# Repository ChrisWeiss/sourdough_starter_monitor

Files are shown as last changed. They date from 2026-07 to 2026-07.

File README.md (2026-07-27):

# Sourdough Starter Monitor (BLE / BTHome)

Battery-oriented remake of [twilio/sourd.io](https://github.com/twilio/sourd.io): temperature, humidity, and rise (**VL53L1X ToF** distance) for a sourdough starter jar.

Instead of Twilio Narrowband cellular, the jar node **advertises BTHome v2 over BLE**. Home Assistant ingests the readings; an automation republishes **sourd.io-style JSON** to your existing MQTT broker.

## Hardware

| Role | Prototype | Production |
|---|---|---|
| MCU | Lolin / WeMos ESP32-WROOM DevKit | nRF52840 (Pro Micro / SuperMini, Feather, or XIAO) + LiPo |
| Climate | BME280 (I2C; BMP280 fallback: no humidity) | same |
| Distance | VL53L1X ToF (I2C) | same; keep lid-to-dough ≥ ~30–40 mm |
| Enclosure | Bench wiring | sourd.io v2.5 jar stack + remixed lid insert |

See [docs/wiring.md](docs/wiring.md) (WireViz assembly diagrams) and [docs/bringup.md](docs/bringup.md). Regenerate diagrams with `./scripts/render_wiring.sh`.

## Firmware

PlatformIO project in [`firmware/`](firmware/). Use the project virtualenv (PlatformIO + WireViz):

```bash
./scripts/setup_venv.sh
source .venv/bin/activate

# One-shot build + flash + monitor (auto-detects USB serial)
./scripts/bringup_esp32.sh          # Lolin ESP32 prototype
./scripts/bringup_nrf52840.sh       # Pro Micro nRF52840 (default)

cd firmware
pio run -e lolin-esp32          # build prototype
pio run -e nrf52840             # Adafruit Feather
pio run -e nrf52840-xiao        # Seeed XIAO nRF52840
pio run -e nrf52840-promicro    # Pro Micro / SuperMini nRF52840
```

Duty cycle: wake → read sensors → advertise ~1.5 s → sleep (**90 s** on all envs, `SAMPLE_INTERVAL_SEC`).

## Home Assistant + MQTT

1. Discover the BTHome device (name `sourdough`).
2. Automation **Sourdough BTHome → MQTT** republishes to the broker (see [ha/](ha/)).
3. Subscribe to `sourdough/sourdough/state`:

```json
{"humidity":55.2,"temp":24.5,"distance":12,"battery":97,"pressure":1013.25}
```

Details: [docs/home-assistant.md](docs/home-assistant.md), [ha/README.md](ha/README.md).

## Enclosure

Vendored sourd.io STLs plus OpenSCAD remix and rendered adapters: [enclosure/README.md](enclosure/README.md).

```bash
./scripts/render_enclosure.sh
```

## License

Firmware and project docs: Apache-2.0 (aligned with sourd.io). Vendored enclosure STLs retain upstream Apache-2.0 copyright from Christine Sunu / Twilio sourd.io.

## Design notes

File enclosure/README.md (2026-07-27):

# Enclosure

## Vendored sourd.io v2.5

STL files in [`v2.5/`](v2.5/) are from [twilio/sourd.io](https://github.com/twilio/sourd.io) (Apache-2.0). Designed for a Ball jar with a **2½″ canning lid** (removable center).

| File | Role |
|---|---|
| `insert_v25.stl` | Original Grove sensor insert |
| `layer1_v25.stl` … `layer4_v25.stl` | Stack / board bay for Narrowband kit |
| `hat-v25.stl` | Decorative hat |

## Remix for this project

This project uses **VL53L1X** (optical window) + **BME280** (BMP280 also works, without humidity). (OpenSCAD/STL filenames still say `vl53l3cx` for historical reasons.)

OpenSCAD source: [`adapter/lid_insert_vl53l3cx_bme280.scad`](adapter/lid_insert_vl53l3cx_bme280.scad)

| Output | Role |
|---|---|
| [`adapter/lid_insert_vl53l3cx_bme280.stl`](adapter/lid_insert_vl53l3cx_bme280.stl) | ToF aperture + BME280 vent on a ~70 mm disk |
| [`adapter/board_adapter_nrf52840.stl`](adapter/board_adapter_nrf52840.stl) | Shallow pocket for Feather / XIAO-sized nRF52840 |

Render both STLs (or re-tune after measuring your modules):

```bash
./scripts/render_enclosure.sh
```

In the OpenSCAD GUI, use **Customizer → Part** (or edit `PART` at the top of the `.scad`) to switch between `lid_insert` and `board_adapter` for preview. CLI/`render_enclosure.sh` pass `-D PART=…` so both STLs still export without editing the file.

Tune `tof_window_d` and board pocket dimensions in the `.scad` before printing. Keep the dough surface **≥ 10 mm** from the sensor (prefer ≥ 30 mm). Fit-check against a Ball jar lid and the vendored v2.5 stack before committing to a long print.

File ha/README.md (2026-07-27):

# Home Assistant — BTHome + MQTT republish

The jar sensor advertises **BTHome v2** (UUID `0xFCD2`). Home Assistant discovers it via Bluetooth proxies. Use the automation below to mirror readings onto your existing MQTT broker in sourd.io-style JSON.

## Prerequisites

1. [Bluetooth](https://www.home-assistant.io/integrations/bluetooth/) integration with coverage near the jar (built-in adapter or ESPHome Bluetooth proxy).
2. [MQTT](https://www.home-assistant.io/integrations/mqtt/) integration pointed at your local broker.
3. Device appears under Settings → Devices as a BTHome device (name defaults to `sourdough`).

## Entity IDs

After discovery, adjust these entity IDs to match your install (Developer Tools → States):

| Reading | Typical entity |
|---|---|
| Temp | `sensor.sourdough_temperature` |
| Humidity  | `sensor.sourdough_humidity` (present with BME280; absent if BMP280 fallback) |
| Distance  | `sensor.sourdough_distance` — set unit to **mm** in entity settings |
| Battery | `sensor.sourdough_battery` |
| Pressure  | `sensor.sourdough_pressure` |

Firmware advertises BTHome object `0x40` (millimetres). Home Assistant may convert that to inches when your profile uses US customary units, which looks like “1 inch resolution.” Override the entity unit to **mm** (entity cog → Unit of measurement).

Distance in MQTT: `distance_mm` (preferred) plus legacy `distance` in cm for older sourd.io-style consumers.

## MQTT topic

- Topic: `sourdough/sourdough/state`
- Payload example (BME280):

```json
{"humidity":55.2,"temp":24.50,"distance_mm":192,"distance":19,"battery":97,"pressure":1013.25}
```

If the board falls back to BMP280, `humidity` is `null` and the humidity entity is absent.

Replace the middle path segment with a stable device id if you run more than one jar.

## Automation

The live Home Assistant automation is created via the config API (alias **Sourdough BTHome → MQTT**, id `sourdough_bthome_mqtt_republish`). A checked-in reference copy lives in [`mqtt_republish.yaml`](mqtt_republish.yaml) for package/YAML installs.

After the BTHome device appears, confirm a retained message on `sourdough/sourdough/state` whenever temperature/humidity/distance/battery updates.

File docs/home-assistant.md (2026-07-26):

# Home Assistant setup

1. Bring up the prototype ([bringup.md](bringup.md)) near a Bluetooth proxy / HA Bluetooth adapter.
2. Wait for **BTHome** discovery (Settings → Devices & services → devices). Name defaults to `sourdough`.
3. Confirm entities: temperature, humidity (BME280 only), **distance**, battery, pressure.
4. **Distance units:** firmware already advertises BTHome distance in **mm**. If HA shows inches (1 in steps), that is display conversion from your unit system — not firmware resolution.
   - Open the distance entity → cog → **Unit of measurement** → **mm**
   - Optionally set display precision to `0` (whole millimetres)
5. The MQTT republish automation (**Sourdough BTHome → MQTT**) should already be present; adjust entity IDs if HA renamed them. Reference YAML: [`ha/mqtt_republish.yaml`](../ha/mqtt_republish.yaml). Payload includes `distance_mm` and legacy `distance` (cm).
6. Subscribe to `sourdough/sourdough/state` on your broker to verify JSON.

## Bluetooth proxy tips

- ESPHome `bluetooth_proxy:` on an always-on ESP32 near the kitchen works well.
- Advertising window is ~1.5s every sample interval — proxies must be awake/scanning.

## Trust / hardening notes

- BTHome advertisements are unencrypted; treat the kitchen BLE as a trusted LAN segment (or use BTHome encryption keys if you enable them later).
- The MQTT republish uses `retain: true` so last state survives broker restarts — fine for dashboards; disable retain if you prefer ephemeral telemetry.

## Debugging

- Serial monitor at 115200: `./scripts/bringup_esp32.sh` or `./scripts/bringup_nrf52840.sh`.
- If HA never sees the device: check Flags in the advertisement (firmware sets `0x06`), UUID `FCD2`, and that passive scanning is enabled.
- If MQTT stays empty: confirm automation is on and entity IDs match Developer Tools → States.

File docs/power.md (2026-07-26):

# Power notes

## ESP32 DevKit (prototype)

`esp_deep_sleep_start()` after each advertise window. Sleep current on Lolin/WeMos DevKits is typically **milliamps**, not microamps, because of USB-UART and LDO. Use USB power for bring-up only.

Optional battery sense: define `PIN_VBAT` (ADC1) with a 2:1 divider and calibrate `VBAT_EMPTY_MV` / `VBAT_FULL_MV` in `platformio.ini`.

## nRF52840 (production)

### Duty-cycle sleep (default)

Firmware uses **System ON low-power idle** (`NRF_POWER_MODE_LOWPWR` + `waitForEvent`) between samples. That is the correct pattern for RTC/timer wake on nRF52: **System OFF cannot wake from an internal timer** (only GPIO, NFC, or reset).

Enable SoftDevice DCDC when supported. Keep the BME280 in forced mode (already configured).

### ToF (VL53L1X) power

The VL53L1X is a 3.3 V I2C device. Firmware starts ranging only for each sample burst, then `stopRanging()` before sleep. Optional `PIN_TOF_XSHUT` drives the active-low XSHUT pin for hardware standby between samples.

### True System OFF

`power_system_off()` enters System OFF (~µA). Wire an external RTC or button to a wake pin before calling it — otherwise the node will not resume on its own. Prefer the default System ON idle path for the 90 s sample loop.

### Battery %

Uses `PIN_VBAT` when the board defines it (Feather). Calibrate with a meter:

| Cell voltage | Expected % |
|---|---|
| 3.3 V | ~0 |
| 3.7 V | ~44 |
| 4.2 V | ~100 |

Override `-D VBAT_EMPTY_MV=…` / `-D VBAT_FULL_MV=…` if your divider or ADC scale differs. Measure sleep current on LiPo after disconnecting USB.

### Board targets

| Env | Board |
|-----|---|
| `nrf52840` | Adafruit Feather nRF52840 Express |
| `nrf52840-xiao` | XIAO pin map (Adafruit SoftDevice BSP build; flash via XIAO UF2 / Seeed tools) |

Adjust `PIN_*` in `platformio.ini` for your wiring. See [wiring.md](wiring.md).

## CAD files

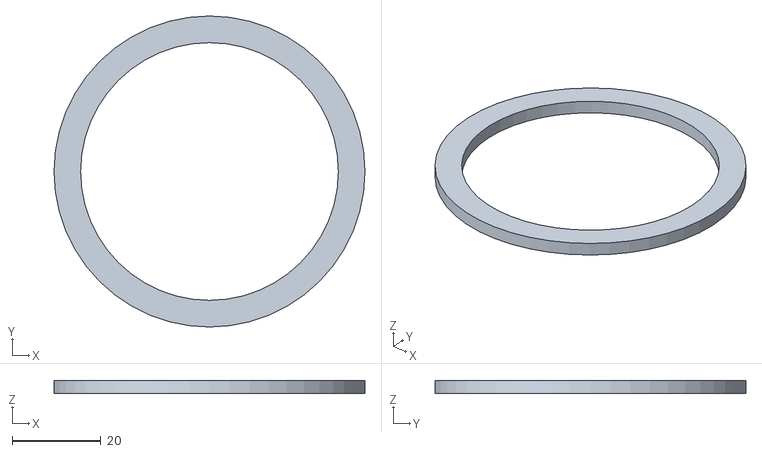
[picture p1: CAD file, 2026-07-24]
enclosure/adapter/lid_insert_vl53l3cx_bme280.stl
70.0 x 70.0 x 3.00

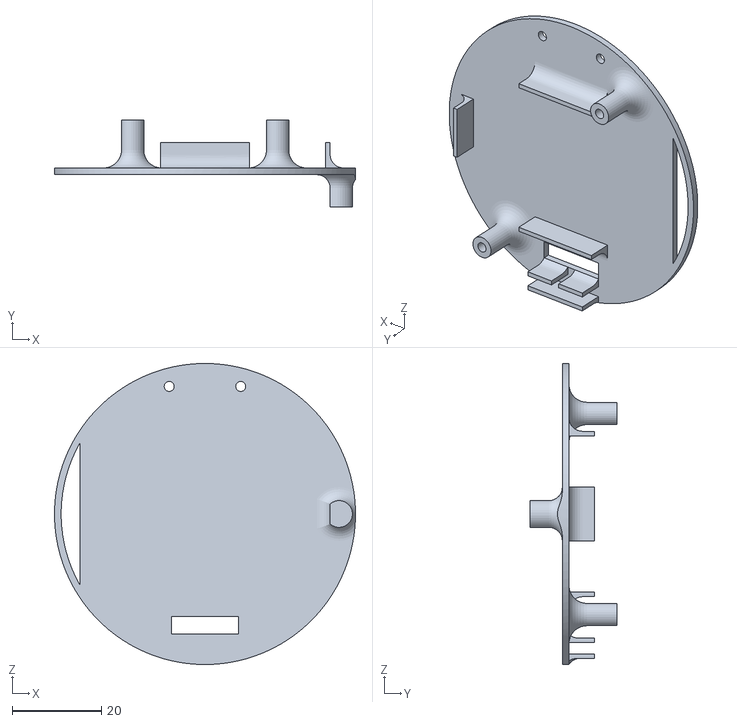
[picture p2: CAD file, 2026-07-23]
enclosure/v2.5/layer3_v25.stl
67.3 x 19.5 x 67.4

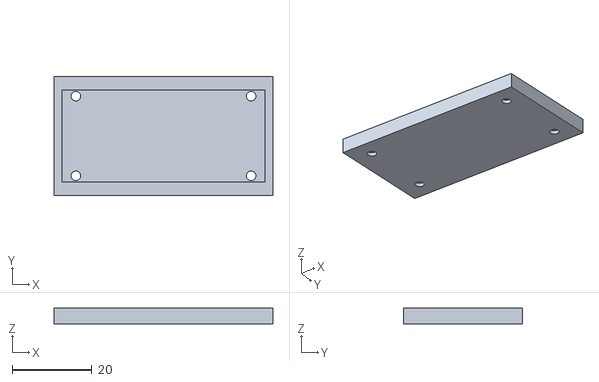
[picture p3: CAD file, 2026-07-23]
enclosure/adapter/board_adapter_nrf52840.stl
55.0 x 30.0 x 4.00

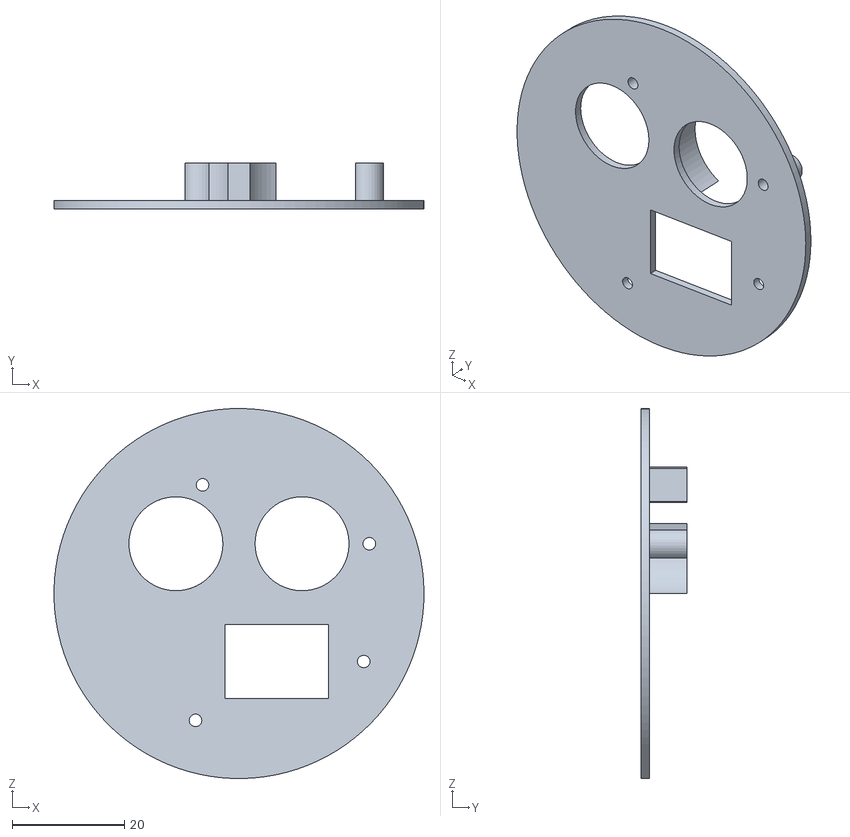
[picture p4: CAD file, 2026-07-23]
enclosure/v2.5/layer1_v25.stl
66.0 x 8.25 x 66.0

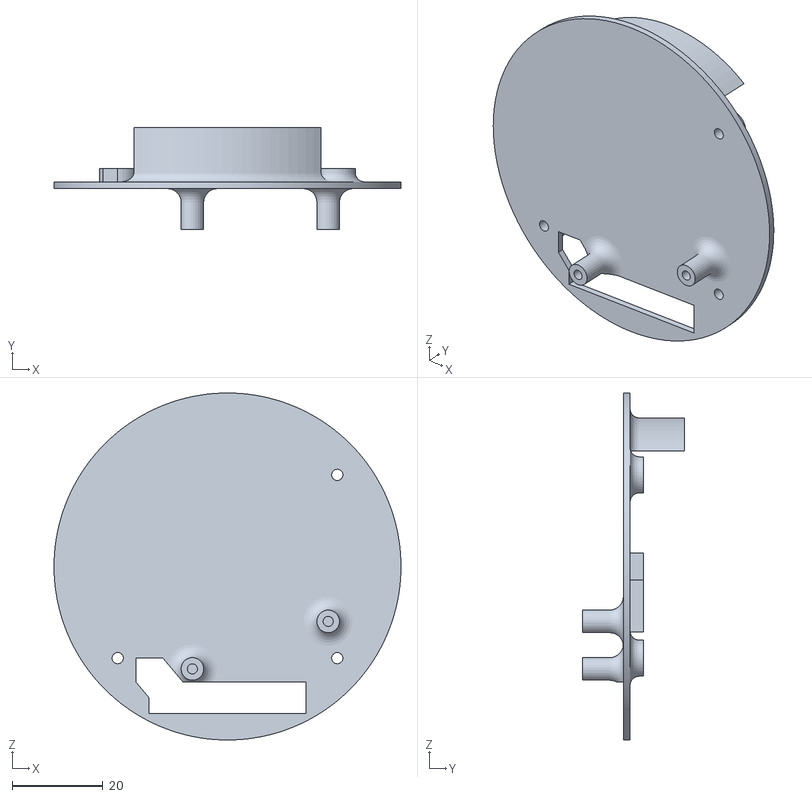
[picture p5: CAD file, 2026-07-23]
enclosure/v2.5/layer2_v25.stl
76.7 x 22.5 x 76.7

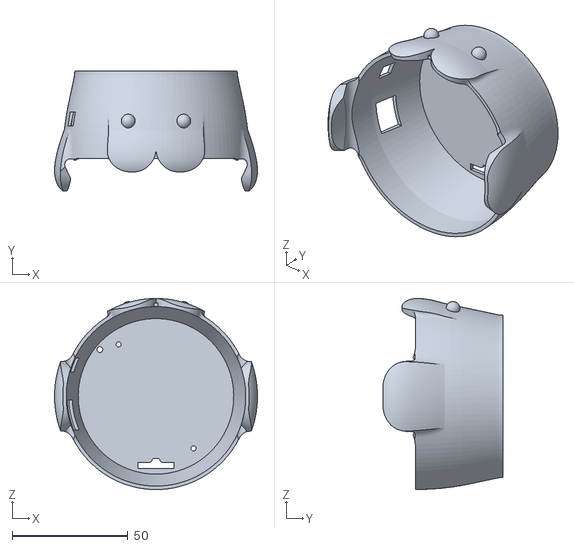
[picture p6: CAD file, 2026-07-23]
enclosure/v2.5/layer4_v25.stl
87.8 x 52.0 x 82.7

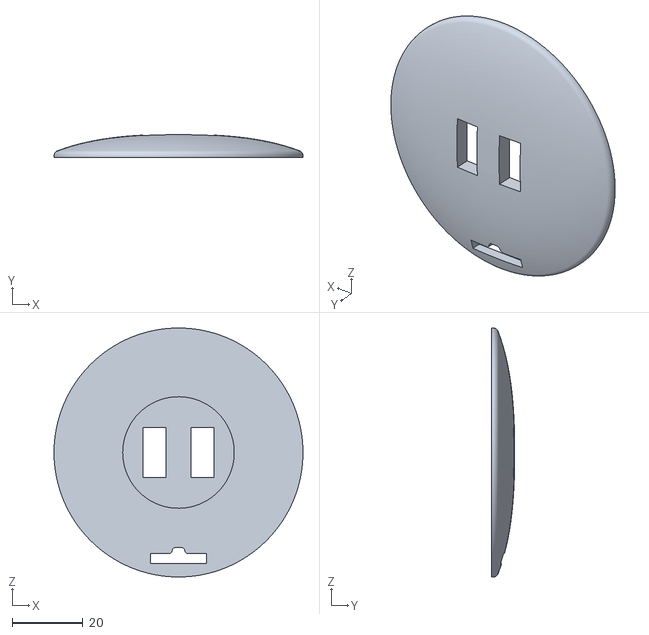
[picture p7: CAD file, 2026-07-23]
enclosure/v2.5/hat-v25.stl
70.3 x 6.50 x 70.3

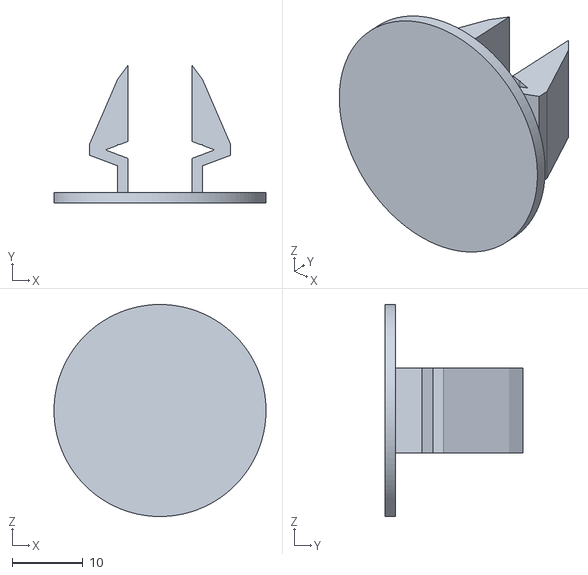
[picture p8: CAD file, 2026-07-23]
enclosure/v2.5/insert_v25.stl
30.0 x 19.5 x 30.0

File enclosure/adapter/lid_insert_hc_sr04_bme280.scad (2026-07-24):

// Lid insert remix for HC-SR04 + BME280 on a ~70mm canning-lid style disk.
// Print as a replacement for sourd.io insert_v25 when using common junk-box sensors.
// Units: millimeters
//
// Which part to render (GUI Customizer dropdown, or edit PART below):
//   lid_insert     — transducer holes + BME280 vent (~70 mm disk)
//   board_adapter  — Feather / XIAO board pocket
//
// CLI:
//   openscad -o lid_insert_hc_sr04_bme280.stl -D 'PART="lid_insert"' lid_insert_hc_sr04_bme280.scad
//   openscad -o board_adapter_nrf52840.stl -D 'PART="board_adapter"' lid_insert_hc_sr04_bme280.scad
// Or: ./scripts/render_enclosure.sh

$fn = 64;

/* [Part] */
// Pick which geometry to preview / export (Customizer → Part, or change this line).
PART = "lid_insert"; // [lid_insert, board_adapter]

lid_od = 70;
lid_id = 62;
thickness = 3;

// HC-SR04 transducer centers ~25mm apart; module ~45 x 20
us_hole_d = 16.5;
us_spacing = 25;
us_offset_y = 8;

// BME280 breakout clearance / vent
bme_w = 16;
bme_h = 12;
bme_offset_y = -18;

// Board bay under upper stack — nRF52840 Feather / XIAO pocket
module board_adapter() {
  difference() {
    cube([55, 30, 4], center = true);
    // Feather-ish outline pocket
    translate([0, 0, 1]) cube([51, 23, 4], center = true);
    // screw holes M2.2-ish
    for (x = [-22, 22], y = [-10, 10])
      translate([x, y, 0]) cylinder(h = 10, d = 2.4, center = true);
  }
}

module lid_insert() {
  difference() {
    cylinder(h = thickness, d = lid_od);
    translate([0, 0, -1]) cylinder(h = thickness + 2, d = lid_id - 4);

    // Ultrasonic transducer holes
    translate([-us_spacing / 2, us_offset_y, -1])
      cylinder(h = thickness + 2, d = us_hole_d);
    translate([us_spacing / 2, us_offset_y, -1])
      cylinder(h = thickness + 2, d = us_hole_d);

    // BME280 vent / recess
    translate([0, bme_offset_y, thickness / 2])
      cube([bme_w, bme_h, thickness + 2], center = true);
  }
}

if (PART == "board_adapter") {
  board_adapter();
} else {
  lid_insert();
}

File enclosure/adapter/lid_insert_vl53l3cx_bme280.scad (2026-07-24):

// Lid insert remix for VL53L3CX + BME280 on a ~70mm canning-lid style disk.
// Units: millimeters
//
// Which part to render (GUI Customizer dropdown, or edit PART below):
//   lid_insert     — ToF optical window + BME280 vent (~70 mm disk)
//   board_adapter  — Feather / XIAO board pocket
//
// CLI:
//   openscad -o lid_insert_vl53l3cx_bme280.stl -D 'PART="lid_insert"' lid_insert_vl53l3cx_bme280.scad
//   openscad -o board_adapter_nrf52840.stl -D 'PART="board_adapter"' lid_insert_vl53l3cx_bme280.scad
// Or: ./scripts/render_enclosure.sh

$fn = 64;

/* [Part] */
PART = "lid_insert"; // [lid_insert, board_adapter]

lid_od = 70;
lid_id = 62;
thickness = 3;

// VL53L3CX aperture — keep dough farther than 10 mm (prefer ≥ 30 mm)
tof_window_d = 8;
tof_offset_y = 8;

// BME280 breakout clearance / vent
bme_w = 16;
bme_h = 12;
bme_offset_y = -18;

module board_adapter() {
  difference() {
    cube([55, 30, 4], center = true);
    translate([0, 0, 1]) cube([51, 23, 4], center = true);
    for (x = [-22, 22], y = [-10, 10])
      translate([x, y, 0]) cylinder(h = 10, d = 2.4, center = true);
  }
}

module lid_insert() {
  difference() {
    cylinder(h = thickness, d = lid_od);
    translate([0, 0, -1]) cylinder(h = thickness + 2, d = lid_id - 4);

    // ToF optical window (centered on sensor FOV)
    translate([0, tof_offset_y, -1])
      cylinder(h = thickness + 2, d = tof_window_d);

    // BME280 vent / recess
    translate([0, bme_offset_y, thickness / 2])
      cube([bme_w, bme_h, thickness + 2], center = true);
  }
}

if (PART == "board_adapter") {
  board_adapter();
} else {
  lid_insert();
}

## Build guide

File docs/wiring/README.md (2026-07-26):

# Assembly wiring diagrams (WireViz)

YAML sources here describe board ↔ sensor assembly wiring. Rendered SVGs live in [`generated/`](generated/).

## Prerequisites

1. System GraphViz (provides `dot`):

```bash
brew install graphviz
```

2. Project virtualenv (PlatformIO + WireViz). Prefer the setup script once:

```bash
./scripts/setup_venv.sh
source .venv/bin/activate
```

Or let `./scripts/render_wiring.sh` create `.venv` from the repo-root [`requirements.txt`](../../requirements.txt).

## Regenerate

```bash
./scripts/render_wiring.sh
```

Creates `.venv` if needed, then writes `docs/wiring/generated/{esp32,feather,xiao,promicro}.svg`.

Layout is controlled by [`_layout.yml`](_layout.yml) (prepended on every render): GraphViz `rankdir=TB` for a taller/narrower harness instead of WireViz’s default left-to-right. Adjust `ranksep` / `nodesep` there if needed.

Pin numbers must stay aligned with `PIN_*` in [`firmware/platformio.ini`](../../firmware/platformio.ini) and the tables in [`../wiring.md`](../wiring.md).

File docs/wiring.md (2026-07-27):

# Wiring

Assembly diagrams are generated with [WireViz](https://github.com/wireviz/WireViz) from YAML under [`wiring/`](wiring/). Regenerate with `./scripts/render_wiring.sh` (see [`wiring/README.md`](wiring/README.md)).

Pin tables below stay aligned with `PIN_*` in `firmware/platformio.ini`.

**Distance sensor:** VL53L1X ToF (I2C). Keep lid-to-dough clearance **≥ ~30–40 mm** including window/foam. Needs a clear optical path through the lid (not ultrasonic holes).

## Prototype — Lolin / WeMos ESP32-WROOM

ESP32 assembly wiring

| Signal | ESP32 GPIO | Notes |
|---|---|---|
| BME280 SDA | 21 | Shared I2C; address `0x76` or `0x77` |
| BME280 SCL | 22 | |
| BME280 VCC | 3V3 | |
| BME280 GND | GND | |
| VL53L1X SDA | 21 | Same bus; address `0x29` |
| VL53L1X SCL | 22 | |
| VL53L1X VCC | 3V3 | |
| VL53L1X GND | GND | |
| VL53L1X XSHUT | (optional) | Active-low shutdown; leave pulled up if unused |

Override pins in `platformio.ini` `build_flags` (`PIN_BME_*`, optional `PIN_TOF_XSHUT`).

Bring-up steps: [bringup.md](bringup.md).

## Production — nRF52840

### Pro Micro / SuperMini (`env:nrf52840-promicro`)

nice!nano-compatible Pro Micro footprint (silkscreen `017` / `020` = P0.17 / P0.20).

Pro Micro nRF52840 assembly wiring

| Signal | Board pin | Notes |
|---|---|---|
| Shared SDA | 017 (P0.17) | BME280 + VL53L1X; firmware `PIN_BME_SDA=29` (Feather BSP index) |
| Shared SCL | 020 (P0.20) | firmware `PIN_BME_SCL=28` |
| Both VCC | VCC (3.3 V) | Do not use RAW/5 V for sensors |
| Both GND | GND | |
| VL53L1X XSHUT | (optional) | e.g. 022 (P0.22); firmware pin `30` if used |

### Adafruit Feather (`env:nrf52840`)

Feather nRF52840 assembly wiring

| Signal | Feather pin | Notes |
|---|---|---|
| Shared SDA | 25 (SDA) | BME280 + VL53L1X (BMP280 also works) |
| Shared SCL | 26 (SCL) | |
| Both VCC | 3V3 | |
| Both GND | GND | |

### Seeed XIAO nRF52840 (`env:nrf52840-xiao`)

XIAO nRF52840 assembly wiring

| Signal | XIAO pin | Notes |
|---|---|---|
| Shared SDA | D4 (SDA) | Confirm silkscreen on your rev |
| Shared SCL | D5 (SCL) | |
| Both VCC | 3V3 | |
| Both GND | GND | |

## Power

- Both sensors are **3.3 V only** — no 5 V rail or Echo divider.
- Optional `PIN_TOF_XSHUT` for hardware standby between samples (see [power.md](power.md)).

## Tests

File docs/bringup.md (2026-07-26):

# Bench bring-up (ESP32 prototype)

Goal: USB-powered Lolin/WeMos ESP32-WROOM advertising BTHome so Home Assistant can discover temperature, humidity, and **ToF distance**.

## Wiring checklist

Follow [wiring.md](wiring.md) and the ESP32 assembly diagram:

ESP32 assembly wiring

Before powering USB:

1. BME280 VCC → 3V3, GND → GND, SDA → GPIO21, SCL → GPIO22
2. VL53L1X VCC → 3V3, GND → GND, SDA → GPIO21, SCL → GPIO22 (same I2C bus)
3. Leave XSHUT pulled up / disconnected unless using `PIN_TOF_XSHUT`
4. Confirm the ToF aperture has a clear view into the jar and the dough surface stays **≥ 10 mm** away (prefer ≥ 30 mm)

## Flash and monitor

```bash
source .venv/bin/activate   # or ./scripts/setup_venv.sh
./scripts/bringup_esp32.sh
```

Expect serial lines like:

```text
temp=24.50C hum=55.20% press=1013.25hPa dist=120mm batt=100%
Advertising … bytes for 1500 ms
```

If ToF stays missing, check I2C scan output (addresses `0x76`/`0x77` and `0x29`) and that the aperture is not covered.

## nRF52840 (Pro Micro / Feather / XIAO)

```bash
source .venv/bin/activate
./scripts/bringup_nrf52840.sh                         # default: nrf52840-promicro
./scripts/bringup_nrf52840.sh --env nrf52840          # Feather
./scripts/bringup_nrf52840.sh --env nrf52840-xiao     # XIAO
```

Wiring: [wiring.md](wiring.md). If upload fails, double-tap RST for the UF2 bootloader, then re-run. Sample interval is **90 s** (`SAMPLE_INTERVAL_SEC`) on all envs.

## Home Assistant

See [home-assistant.md](home-assistant.md). Distance is advertised in **millimetres** (BTHome); the MQTT republish automation converts to centimetres for sourd.io-style JSON.

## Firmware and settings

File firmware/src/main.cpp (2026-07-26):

#include <Arduino.h>

#include "bthome.h"
#include "config.h"
#include "power.h"
#include "sensors.h"

static uint8_t packet_id = 0;

void setup() {
  Serial.begin(115200);
  // USB CDC on nRF: wait briefly so boot diagnostics are visible.
  uint32_t wait_until = millis() + 3000;
  while (!Serial && static_cast<int32_t>(wait_until - millis()) > 0) {
    delay(10);
  }
  delay(50);
  Serial.println();
  Serial.println(F("sourdough BTHome monitor"));

  if (!sensors_begin()) {
    Serial.println(F("WARN: climate sensor not found — temp/pressure omitted"));
  }

  if (!bthome_advertise_begin(DEVICE_NAME)) {
    Serial.println(F("ERROR: BLE init failed"));
  }
}

void loop() {
  SensorReading r = sensors_read();
  uint8_t batt = power_battery_percent();

  Serial.printf("temp=%.2fC hum=", r.temperature_c);
  if (r.humidity_ok) {
    Serial.printf("%.2f%%", r.humidity_pct);
  } else {
    Serial.print(F("n/a"));
  }
  Serial.printf(" press=%.2fhPa dist=%ldmm batt=%u%%\n",
                r.pressure_hpa, r.distance_mm, batt);

  uint8_t payload[24];
  size_t n = bthome_build_payload(payload, sizeof(payload), r, batt, packet_id++);
  if (n == 0) {
    Serial.println(F("ERROR: BTHome payload build failed"));
  } else if (!bthome_advertise(payload, n)) {
    Serial.println(F("ERROR: advertise failed"));
  } else {
    Serial.printf("Advertising %u bytes for %u ms\n", (unsigned)n, ADVERTISE_DURATION_MS);
    delay(ADVERTISE_DURATION_MS);
    bthome_advertise_stop();
  }

#if defined(BOARD_ESP32)
  // Full deep sleep — setup() runs again on wake.
  power_deep_sleep_seconds(SAMPLE_INTERVAL_SEC);
#else
  // nRF: light sleep between samples (see power.cpp notes for system-off).
  power_deep_sleep_seconds(SAMPLE_INTERVAL_SEC);
#endif
}

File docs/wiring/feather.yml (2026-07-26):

# Assembly wiring — Adafruit Feather nRF52840
# Pins match firmware/platformio.ini env:nrf52840 (PIN_*).

metadata:
  title: Feather nRF52840 assembly wiring
  description: BME280 + VL53L1X on shared I2C

connectors:
  MCU:
    type: Adafruit Feather nRF52840
    subtype: Express
    pinlabels: [3V3, GND, SDA_25, SCL_26]
    notes: PIN_BME_SDA=25 PIN_BME_SCL=26; optional PIN_TOF_XSHUT
  BME280:
    type: BME280
    subtype: I2C module
    pinlabels: [VCC, GND, SDA, SCL]
    notes: 3.3V I2C; Wire.begin() board defaults
  VL53:
    type: VL53L1X
    subtype: ToF module
    pinlabels: [VCC, GND, SDA, SCL]
    notes: 3.3V I2C addr 0x29; min range 10 mm

cables:
  BME_PWR:
    gauge: 24 AWG
    length: 0.12
    colors: [RD, BK]
  TOF_PWR:
    gauge: 24 AWG
    length: 0.12
    colors: [RD, BK]
  I2C_BME:
    gauge: 24 AWG
    length: 0.12
    colors: [BU, YE]
  I2C_TOF:
    gauge: 24 AWG
    length: 0.12
    colors: [BU, YE]

connections:
  - # BME280 power
    - MCU: [1, 2]
    - BME_PWR: [1-2]
    - BME280: [1, 2]
  - # VL53 power
    - MCU: [1, 2]
    - TOF_PWR: [1-2]
    - VL53: [1, 2]
  - # BME280 I2C
    - MCU: [3, 4]
    - I2C_BME: [1-2]
    - BME280: [3, 4]
  - # VL53 I2C
    - MCU: [3, 4]
    - I2C_TOF: [1-2]
    - VL53: [3, 4]

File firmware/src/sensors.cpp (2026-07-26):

#include "sensors.h"
#include "config.h"

#include <Arduino.h>
#include <Wire.h>
#include <Adafruit_BME280.h>
#include <Adafruit_BMP280.h>
#include <Adafruit_VL53L1X.h>
#include <math.h>

static Adafruit_BME280 bme;
static Adafruit_BMP280 bmp;
static Adafruit_VL53L1X tof = Adafruit_VL53L1X();
static bool climate_ok = false;
static bool humidity_ok = false;
static bool using_bmp = false;
static bool tof_ok = false;

static void tof_xshut(bool enable_sensor) {
#if defined(PIN_TOF_XSHUT)
  // XSHUT is active-low shutdown on VL53L1X
  digitalWrite(PIN_TOF_XSHUT, enable_sensor ? HIGH : LOW);
  if (enable_sensor) {
    delay(2);
  }
#else
  (void)enable_sensor;
#endif
}

static void i2c_scan_log() {
  Serial.println(F("I2C scan:"));
  uint8_t found = 0;
  for (uint8_t addr = 1; addr < 127; addr++) {
    Wire.beginTransmission(addr);
    if (Wire.endTransmission() == 0) {
      Serial.printf("  - 0x%02X\n", addr);
      found++;
    }
  }
  if (found == 0) {
    Serial.println(F("  (no devices)"));
  }
}

static void i2c_bus_begin() {
#if defined(BOARD_ESP32)
  Wire.begin(PIN_BME_SDA, PIN_BME_SCL);
#elif defined(PIN_BME_SDA) && defined(PIN_BME_SCL)
  // Adafruit nRF52 Wire uses Arduino pin indices (see board variant map).
  Wire.setPins(PIN_BME_SDA, PIN_BME_SCL);
  Wire.begin();
#else
  Wire.begin();
#endif
#ifndef I2C_CLOCK_HZ
#define I2C_CLOCK_HZ 100000
#endif
  Wire.setClock(I2C_CLOCK_HZ);

#if defined(PIN_BME_SDA) && defined(PIN_BME_SCL)
  Serial.printf("I2C pins: SDA=%u SCL=%u @ %u Hz\n",
                (unsigned)PIN_BME_SDA, (unsigned)PIN_BME_SCL,
                (unsigned)I2C_CLOCK_HZ);
#if defined(BOARD_NRF52840)
  extern const uint32_t g_ADigitalPinMap[];
  Serial.printf("I2C GPIO: SDA=P%u.%02u SCL=P%u.%02u\n",
                (unsigned)(g_ADigitalPinMap[PIN_BME_SDA] >= 32),
                (unsigned)(g_ADigitalPinMap[PIN_BME_SDA] & 31),
                (unsigned)(g_ADigitalPinMap[PIN_BME_SCL] >= 32),
                (unsigned)(g_ADigitalPinMap[PIN_BME_SCL] & 31));
#endif
#endif
}

static long measure_distance_mm() {
  if (!tof_ok) {
    return -1;
  }

  tof_xshut(true);
  if (!tof.startRanging()) {
    return -1;
  }

  int16_t samples[VL53_SAMPLE_COUNT];
  uint8_t n = 0;
  const uint32_t per_sample_ms = static_cast<uint32_t>(VL53_TIMING_BUDGET_MS) + 100UL;

  while (n < VL53_SAMPLE_COUNT) {
    const uint32_t deadline = millis() + per_sample_ms;
    while (!tof.dataReady()) {
      if (static_cast<int32_t>(deadline - millis()) <= 0) {
        break;
      }
      delay(1);
    }
    if (!tof.dataReady()) {
      break;
    }

    uint8_t range_status = 0xFF;
    (void)tof.VL53L1X_GetRangeStatus(&range_status);
    const int16_t mm = tof.distance();
    tof.clearInterrupt();

    // ULD: 0 = range valid.
    if (range_status != 0 || mm < 0) {
      continue;
    }
    if (mm < VL53_MIN_RANGE_MM || mm > VL53_MAX_RANGE_MM) {
      continue;
    }
    samples[n++] = mm;
  }

  (void)tof.stopRanging();
  tof_xshut(false);

  if (n == 0) {
    return -1;
  }

  // Insertion sort then median (odd count preferred; even → average of middle).
  for (uint8_t i = 1; i < n; i++) {
    const int16_t key = samples[i];
    int8_t j = static_cast<int8_t>(i) - 1;
    while (j >= 0 && samples[j] > key) {
      samples[j + 1] = samples[j];
      j--;
    }
    samples[j + 1] = key;
  }
  if ((n & 1U) != 0) {
    return samples[n / 2];
  }
  return (static_cast<long>(samples[n / 2 - 1]) + samples[n / 2]) / 2;
}

static bool climate_begin_bme(uint8_t addr) {
  if (!bme.begin(addr, &Wire)) {
    return false;
  }
  bme.setSampling(Adafruit_BME280::MODE_FORCED,
                  Adafruit_BME280::SAMPLING_X1,
                  Adafruit_BME280::SAMPLING_X1,
                  Adafruit_BME280::SAMPLING_X1,
                  Adafruit_BME280::FILTER_OFF,
                  Adafruit_BME280::STANDBY_MS_1000);
  using_bmp = false;
  humidity_ok = true;
  Serial.printf("BME280 OK @0x%02X (chip=0x%02X)\n", addr,
                (unsigned)bme.sensorID());
  return true;
}

static bool climate_begin_bmp(uint8_t addr) {
  if (!bmp.begin(addr)) {
    return false;
  }
  bmp.setSampling(Adafruit_BMP280::MODE_FORCED,
                  Adafruit_BMP280::SAMPLING_X1,
                  Adafruit_BMP280::SAMPLING_X1,
                  Adafruit_BMP280::FILTER_OFF,
                  Adafruit_BMP280::STANDBY_MS_1000);
  using_bmp = true;
  humidity_ok = false;
  Serial.printf("BMP280 OK @0x%02X (temp+pressure; no humidity)\n", addr);
  return true;
}

bool sensors_begin() {
#if defined(PIN_TOF_XSHUT)
  pinMode(PIN_TOF_XSHUT, OUTPUT);
  digitalWrite(PIN_TOF_XSHUT, HIGH);
#endif

  i2c_bus_begin();
  i2c_scan_log();

  climate_ok = false;
  humidity_ok = false;
  using_bmp = false;

  const uint8_t addrs[] = {BME280_I2C_ADDR, 0x77};
  for (uint8_t i = 0; i < 2 && !climate_ok; i++) {
    if (climate_begin_bme(addrs[i])) {
      climate_ok = true;
    }
  }
  for (uint8_t i = 0; i < 2 && !climate_ok; i++) {
    if (climate_begin_bmp(addrs[i])) {
      climate_ok = true;
    }
  }
  if (!climate_ok) {
    Serial.println(F("Climate sensor not found (tried BME280 then BMP280)"));
  }

  tof_ok = false;
  if (tof.begin(VL53_I2C_ADDR, &Wire)) {
    (void)tof.VL53L1X_SetDistanceMode(1); // short: better near-field / ambient
    (void)tof.VL53L1X_SetROI(VL53_ROI_XY, VL53_ROI_XY);
    const uint16_t budget_ms = static_cast<uint16_t>(VL53_TIMING_BUDGET_MS);
    if (!tof.setTimingBudget(budget_ms)) {
      Serial.printf("VL53L1X setTimingBudget(%u) failed\n", budget_ms);
    }
    // Inter-measurement must be >= timing budget while ranging.
    (void)tof.VL53L1X_SetInterMeasurementInMs(budget_ms);
    // Do not leave continuous ranging on between samples (nRF light-sleep loop).
    tof_ok = true;
    Serial.printf("VL53L1X OK (short, ROI=%ux%u, budget=%ums, median=%u)\n",
                  (unsigned)VL53_ROI_XY, (unsigned)VL53_ROI_XY,
                  (unsigned)budget_ms, (unsigned)VL53_SAMPLE_COUNT);
  } else {
    Serial.printf("VL53L1X begin failed status=%u\n", (unsigned)tof.vl_status);
  }

  if (!climate_ok || !tof_ok) {
    Serial.println(F("WARN: sensor init issue — rescanning I2C"));
    i2c_scan_log();
  }

  return climate_ok;
}
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

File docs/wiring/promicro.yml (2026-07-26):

# Assembly wiring — Pro Micro / SuperMini nRF52840 (nice!nano-compatible)
# Pins match firmware/platformio.ini env:nrf52840-promicro (PIN_*).
# BME280 + VL53L1X share the I2C bus (3.3V only).

metadata:
  title: Pro Micro nRF52840 assembly wiring
  description: BME280 + VL53L1X on shared I2C

connectors:
  MCU:
    type: Pro Micro / SuperMini nRF52840
    subtype: nice!nano-compatible
    pinlabels: [VCC, GND, 017_SDA, 020_SCL]
    notes: silkscreen 017/020 = P0.17/P0.20; firmware PIN_BME_SDA=29 PIN_BME_SCL=28 (Feather BSP)
  BME280:
    type: BME280
    subtype: I2C module
    pinlabels: [VCC, GND, SDA, SCL]
    notes: 3.3V I2C; address 0x76 or 0x77
  VL53:
    type: VL53L1X
    subtype: ToF module
    pinlabels: [VCC, GND, SDA, SCL]
    notes: 3.3V I2C addr 0x29; keep lid-to-dough ≥ ~30 mm

cables:
  BME_PWR:
    gauge: 24 AWG
    length: 0.10
    colors: [RD, BK]
    notes: BME280 power (3.3V)
  TOF_PWR:
    gauge: 24 AWG
    length: 0.10
    colors: [RD, BK]
    notes: VL53L1X power (3.3V)
  I2C_BME:
    gauge: 24 AWG
    length: 0.10
    colors: [BU, YE]
    notes: Shared I2C to BME280
  I2C_TOF:
    gauge: 24 AWG
    length: 0.10
    colors: [BU, YE]
    notes: Shared I2C to VL53L1X

connections:
  - # BME280 power
    - MCU: [1, 2]
    - BME_PWR: [1-2]
    - BME280: [1, 2]
  - # VL53 power
    - MCU: [1, 2]
    - TOF_PWR: [1-2]
    - VL53: [1, 2]
  - # BME280 I2C
    - MCU: [3, 4]
    - I2C_BME: [1-2]
    - BME280: [3, 4]
  - # VL53 I2C (same SDA/SCL)
    - MCU: [3, 4]
    - I2C_TOF: [1-2]
    - VL53: [3, 4]

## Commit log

2026-07-23 Add BLE BTHome sourdough monitor firmware and HA MQTT bridge.
    Port sourd.io-style jar sensing (BME280 + HC-SR04) to ESP32/nRF52840 with BTHome ads, enclosure remix, and Home Assistant MQTT republish.
    [hat-v25.stl, insert_v25.stl, layer1_v25.stl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]
2026-07-23 Prepare bench bring-up, HA MQTT bridge, enclosure STLs, and nRF power path.
    Add flash/render scripts, I2C diagnostics and ultrasonic power gating, System ON low-power sleep with calibrated battery %, rendered lid/board STLs, and install-ready MQTT republish docs.
    [board_adapter_nrf52840.stl, lid_insert_hc_sr04_bme280.scad, lid_insert_hc_sr04_bme280.stl]
2026-07-23 Add WireViz assembly diagrams for ESP32 and nRF boards.
    Document pinouts with generated SVGs and a render script so wiring stays aligned with firmware PIN_* flags.
2026-07-24 Add project venv for PlatformIO and refresh WireViz wiring docs.
    Centralize tooling in .venv via requirements.txt/setup_venv.sh, and keep assembly diagrams aligned with board pin maps.
    [lid_insert_hc_sr04_bme280.scad]
2026-07-24 Replace HC-SR04 with VL53L3CX ToF distance sensing.
    Share I2C with the BME280, drop the 5V Echo path, and keep lid-to-dough above the 10 mm minimum range.
    [lid_insert_hc_sr04_bme280.stl, lid_insert_vl53l3cx_bme280.scad, lid_insert_vl53l3cx_bme280.stl]
2026-07-26 Add Cursor skill for regenerating WireViz assembly diagrams.
2026-07-26 Add Pro Micro nRF52840 support and harden VL53L1X bring-up.
    Support BMP280 auto-detect, stop ToF ranging between samples, align wiring/SVGs and HA MQTT docs, and add an nRF flash script.
2026-07-27 Document BME280 as the primary climate sensor.
    BMP280 remains a supported fallback without humidity; MQTT examples now show a humidity value by default.
